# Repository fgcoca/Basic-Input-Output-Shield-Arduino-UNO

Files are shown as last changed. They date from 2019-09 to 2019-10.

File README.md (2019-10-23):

# **Escudo de entradas y salidas básicas para Arduino UNO**
# **(Basic Input Output Shield)**
Migración del Escudo de entradas y salidas básicas para Arduino UNO (Basic Input Output Shield) creado por Domingo Llorente del Departamento de Electrónica del IES Luis de Lucena de Guadalajara.

En las imágenes vemos una vista 3D del diseño en KiCAD y el aspecto real de la placa.

Captura | Fotografa
-- | --
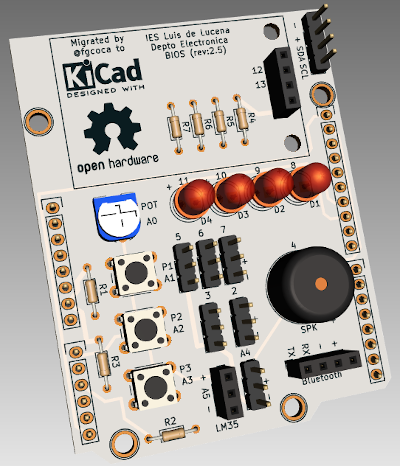
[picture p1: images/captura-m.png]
Imagen 1
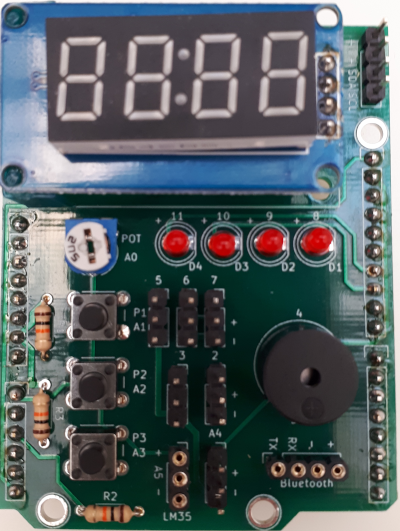
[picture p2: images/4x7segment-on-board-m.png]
Imagen 2
 | 

[1]: https://github.com/fgcoca/Basic-Input-Output-Shield-Arduino-UNO/blob/master/images/captura-m.png
[2]: https://github.com/fgcoca/Basic-Input-Output-Shield-Arduino-UNO/blob/master/images/4x7segment-on-board-m.png

## **Diseño de la PCB** 

En el enlace están todos los archivos KiCAD por si te apetece ver cómo se ha realizado el diseño de esta bonita Shield.

[BIOS_Shield_1.0_Migration](https://github.com/fgcoca/Basic-Input-Output-Shield-Arduino-UNO/tree/master/BIOS_Shield_1.0_Migration)

## **Memorias** 

* [Original en pdf](https://github.com/fgcoca/Basic-Input-Output-Shield-Arduino-UNO/blob/master/Manuales/original/BIOS_Shield_memoria_rev1.2.pdf)
* [Migrada en odt](https://github.com/fgcoca/Basic-Input-Output-Shield-Arduino-UNO/blob/master/Manuales/migrado/BIOS_Shield_migration_memory_rev1.0.odt)
* [Migrada en pdf](https://github.com/fgcoca/Basic-Input-Output-Shield-Arduino-UNO/blob/master/Manuales/migrado/BIOS_Shield_migration_memory_rev1.0.pdf)
* [Directorio de imágenes](https://github.com/fgcoca/Basic-Input-Output-Shield-Arduino-UNO/tree/master/images)

## **Programas para prueba de funcionalidad** 

* [Todo en un zip](https://github.com/fgcoca/Basic-Input-Output-Shield-Arduino-UNO/blob/master/BIOS_Programas_Demo_v1/BIOS_Programas_Demo_y_librerias.zip)
* [Directorio de sketches individuales y librerias](https://github.com/fgcoca/Basic-Input-Output-Shield-Arduino-UNO/tree/master/BIOS_Programas_Demo_v1)

## **Descripción del uso de pines** 

En el enlace tenemos los archivos svg y pdf del pinout de la PCB. El svg se facilita por si te apetece ver cómo se hace de forma sencilla un pinout en Inkscape.

* [Pinout en svg](https://github.com/fgcoca/Basic-Input-Output-Shield-Arduino-UNO/blob/master/pinout/BIOS_Shield_1.0_Migration.svg)
* [Pinout en pdf](https://github.com/fgcoca/Basic-Input-Output-Shield-Arduino-UNO/blob/master/pinout/BIOS_Shield_1.0_Migration.pdf)

## **Soporte 3D para el display de 4x7 segmentos** 

Directorio con el archivo FreeCAD de diseño del soporte y dos versiones stl del mismo.

* [Soporte](https://github.com/fgcoca/Basic-Input-Output-Shield-Arduino-UNO/tree/master/soporte)

### **Autor**

[Federico Coca Caba] (https://github.com/fgcoca)

### **Licencia**
<br /> <a rel="license" href="http://creativecommons.org/licenses/by-sa/4.0/">Creative Commons Attribution-ShareAlike 4.0 International License</a>.

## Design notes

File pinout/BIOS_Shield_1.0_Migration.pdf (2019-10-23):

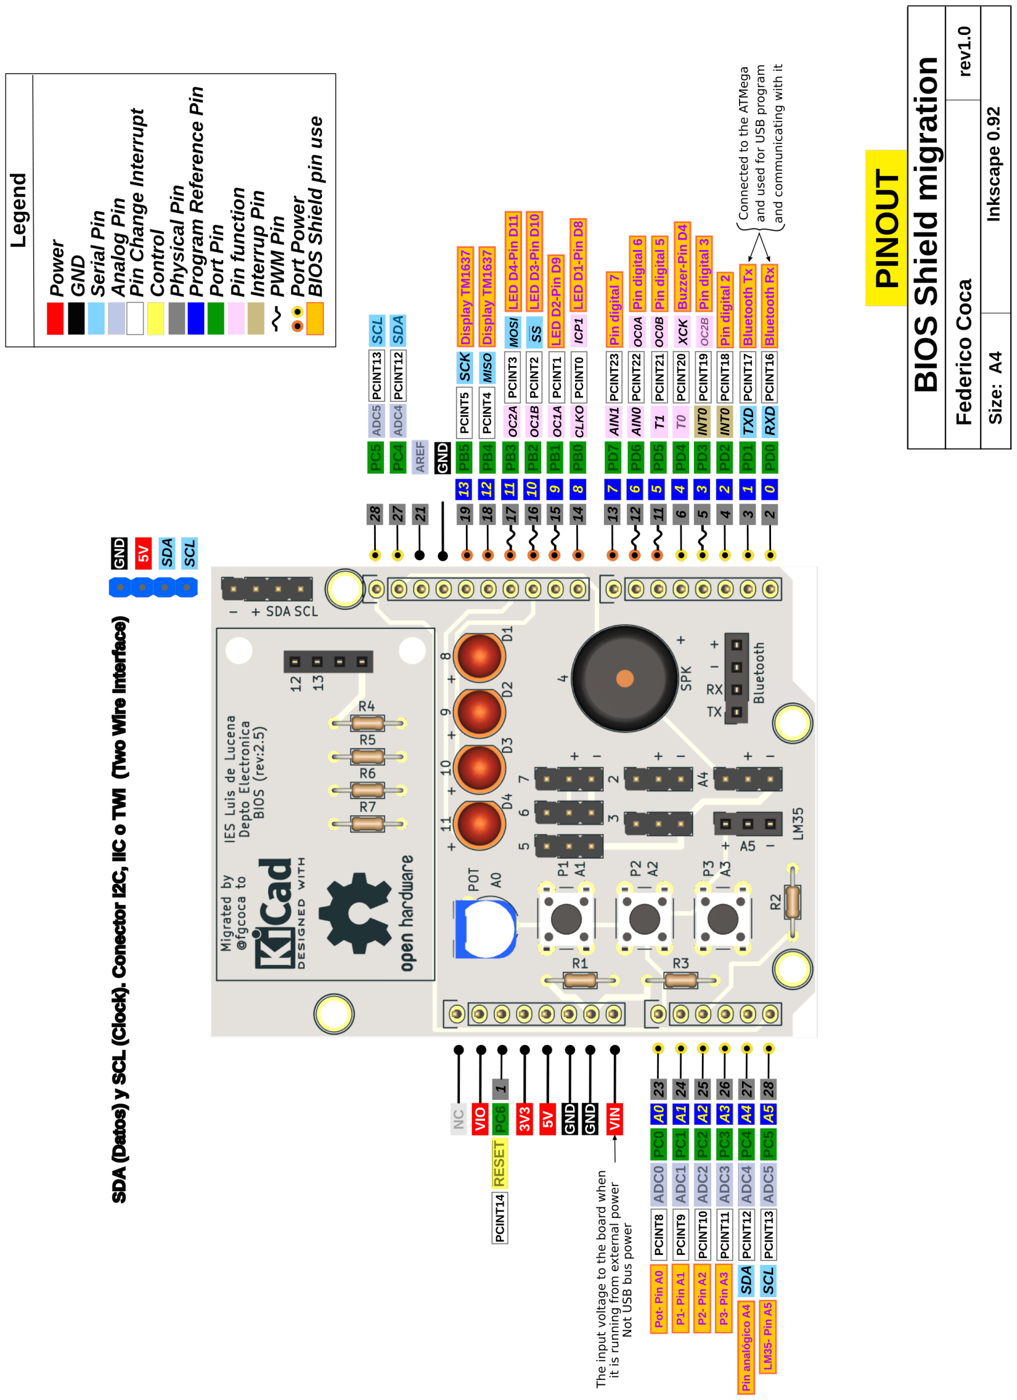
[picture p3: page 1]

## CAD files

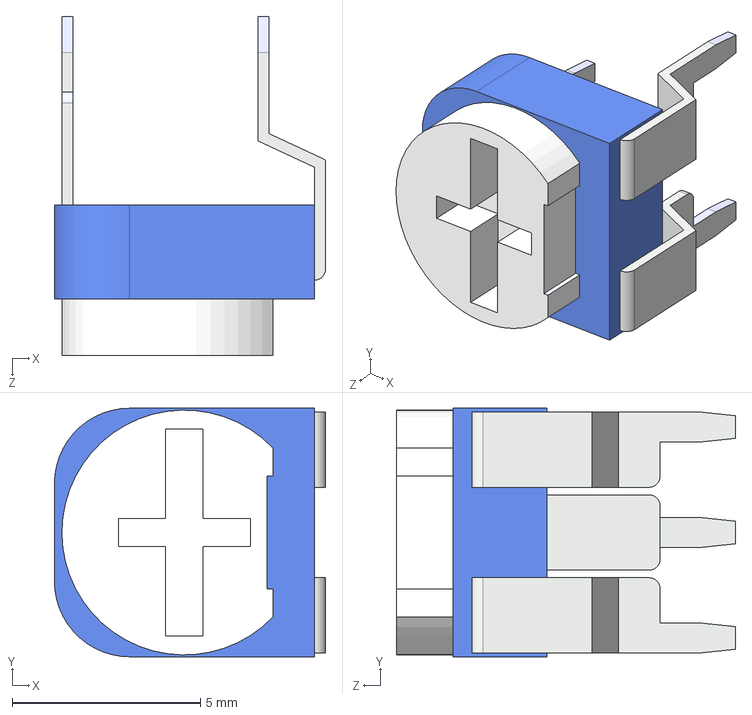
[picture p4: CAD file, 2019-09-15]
BIOS_Shield_1.0_Migration/modelos 3d/Potentiometer Blue.STEP
7.20 x 6.60 x 9.00 mm

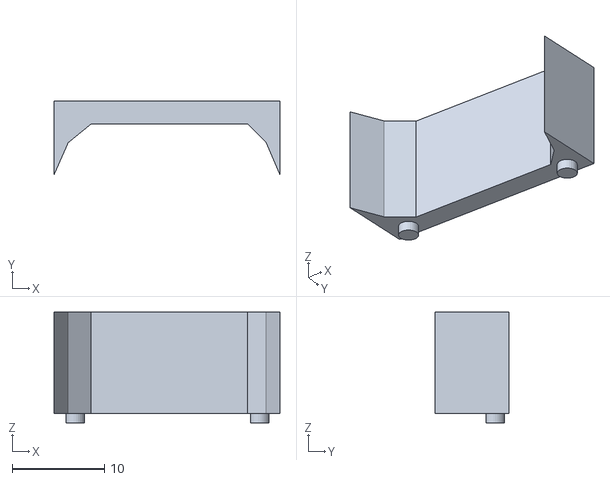
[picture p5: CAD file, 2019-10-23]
soporte/soporte-alto.stl
24.5 x 8.00 x 12.0

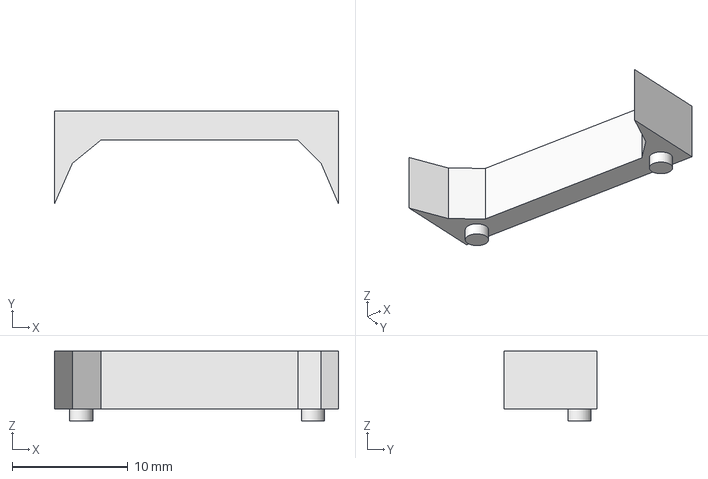
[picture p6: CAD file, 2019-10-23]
soporte/soporte.FCStd
24.5 x 8.00 x 6.00 mm

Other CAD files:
soporte/soporte.stl

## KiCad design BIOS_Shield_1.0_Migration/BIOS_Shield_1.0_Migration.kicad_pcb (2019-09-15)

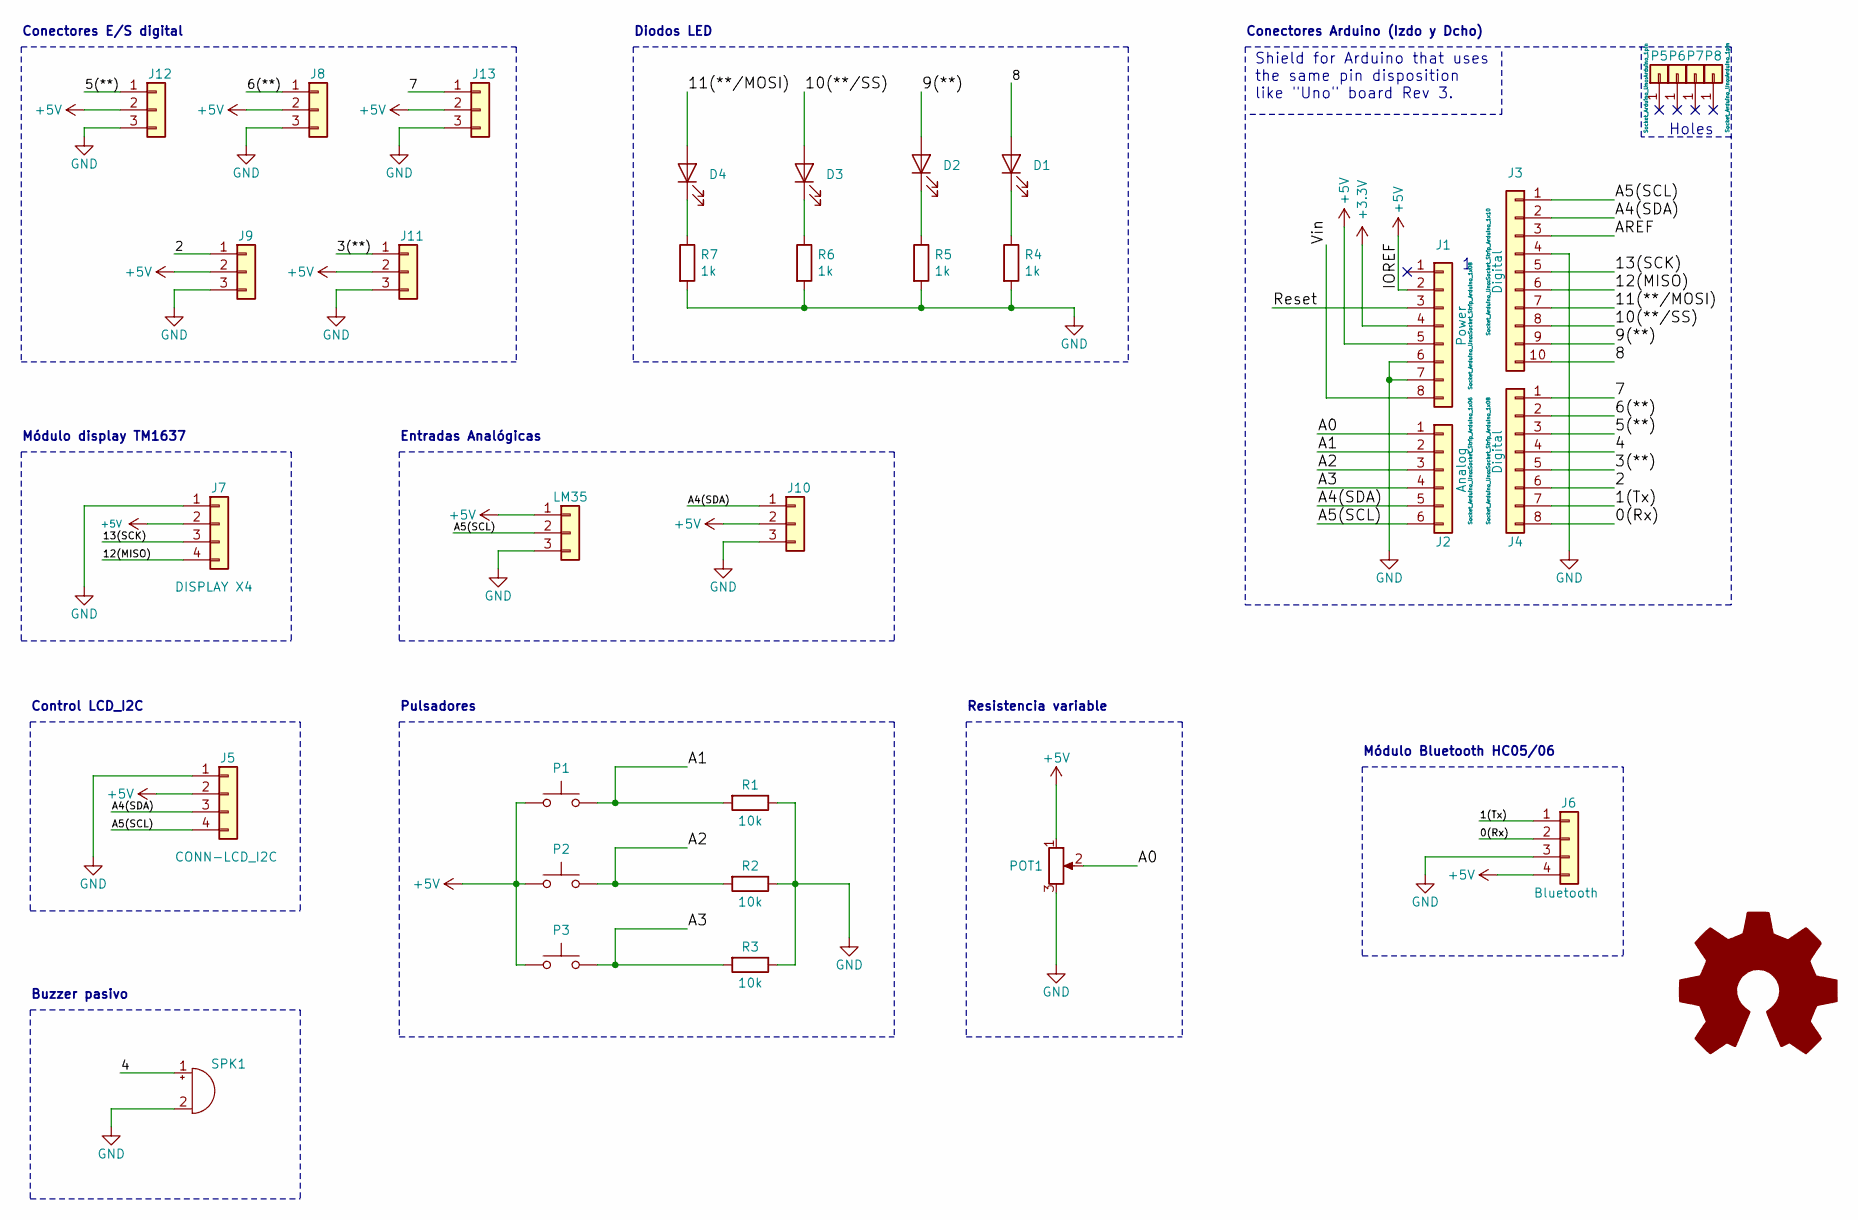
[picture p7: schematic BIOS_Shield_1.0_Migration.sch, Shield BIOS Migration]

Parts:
D1, D2, D3, D4: LED; LED_D5.0mm
J1: Power; Socket_Strip_Arduino_1x08
J2: Analog; Socket_Strip_Arduino_1x06
J3: Digital; Socket_Strip_Arduino_1x10
J4: Digital; Socket_Strip_Arduino_1x08
J5: CONN-LCD_I2C; PinSocket_1x04_P2.54mm_Vertical
J6: Bluetooth; PinSocket_1x04_P2.54mm_Vertical
J7: DISPLAY X4; TM1637
J8, J9, J10, J11, J12, J13: Conn_01x03; PinSocket_1x03_P2.54mm_Vertical
LM35: Conn_01x03; PinSocket_1x03_P2.54mm_Vertical
P1, P2, P3: SW_Push; SW_PUSH_6mm
P5, P6, P7, P8: CONN_01X01; Arduino_1pin
POT1: R_POT; Potentiometer_Piher_PT-6-V_Vertical
R1, R2, R3: 10k; R_Axial_DIN0204_L3.6mm_D1.6mm_P7.62mm_Horizontal
R4, R5, R6, R7: 1k; R_Axial_DIN0204_L3.6mm_D1.6mm_P7.62mm_Horizontal
SPK1: Buzzer; Buzzer_12x9.5RM7.6

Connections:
+3V3: J1.4
+5V: J1.2, J1.5, J5.2, J6.4, J7.2, J8.2, J9.2, J10.2, J11.2, J12.2, J13.2, LM35.1, P1.1, P2.1, P3.1, POT1.1; also elsewhere on the board
/0(Rx): J4.8, J6.2
/1(Tx): J4.7, J6.1
/2: J4.6, J9.1
/3(**): J4.5, J11.1
/4: J4.4, SPK1.1 (-); also elsewhere on the board
/5(**): J4.3, J12.1
/6(**): J4.2, J8.1
/7: J4.1, J13.1
/8: D1.2 (A), J3.10
/9(**): D2.2 (A), J3.9
/10(**/SS): D3.2 (A), J3.8
/11(**/MOSI): D4.2 (A), J3.7
/12(MISO): J3.6, J7.4
/13(SCK): J3.5, J7.3
/A0: J2.1, POT1.2; also elsewhere on the board
/A1: J2.2, P1.2, R1.2
/A2: J2.3, P2.2, R2.2
/A3: J2.4, P3.2, R3.2
/A4(SDA): J2.5, J3.2, J5.3, J10.1
/A5(SCL): J2.6, J3.1, J5.4, LM35.2
/AREF: J3.3
/Reset: J1.3
/Vin: J1.8
GND: J1.6, J1.7, J3.4, J5.1, J6.3, J7.1, J8.3, J9.3, J10.3, J11.3, J12.3, J13.3, LM35.3, POT1.3, R1.1, R2.1, R3.1, R4.2, R5.2, R6.2, R7.2, SPK1.2 (+); also elsewhere on the board
unnamed: D1.1 (K), R4.1
unnamed: D2.1 (K), R5.1
unnamed: D3.1 (K), R6.1
unnamed: D4.1 (K), R7.1

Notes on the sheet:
Holes
Shield for Arduino that uses the same pin disposition like "Uno" board Rev 3.
Conectores Arduino (Izdo y Dcho)
Conectores E/S digital
Diodos LED
Módulo display TM1637
Control LCD_I2C
Buzzer pasivo
Entradas Analógicas
Pulsadores
Resistencia variable
Módulo Bluetooth HC05/06

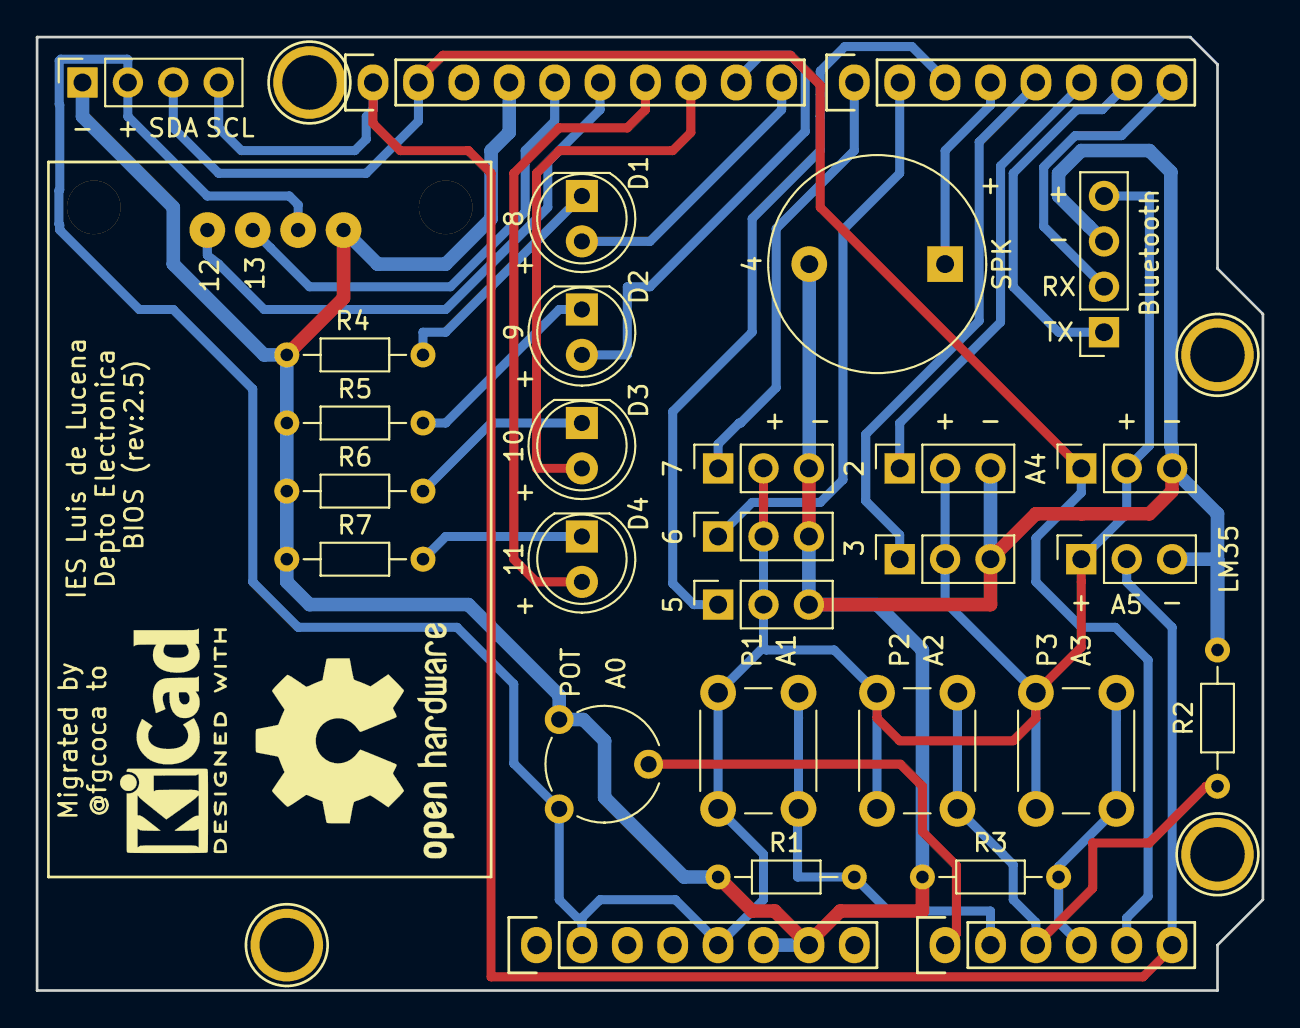
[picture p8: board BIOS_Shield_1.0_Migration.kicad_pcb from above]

Board: 2 copper layers, 68.6 x 53.3 mm, 34 parts (0 on the bottom side), 26 nets.

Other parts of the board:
POT: R_POT; Potentiometer_Piher_PT-6-V_Vertical
SPK: Buzzer; Buzzer_12x9.5RM7.6

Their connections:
+5V: POT.1; also elsewhere on the board
/4: SPK.1; also elsewhere on the board
/A0: POT.2; also elsewhere on the board
GND: POT.3, SPK.2; also elsewhere on the board

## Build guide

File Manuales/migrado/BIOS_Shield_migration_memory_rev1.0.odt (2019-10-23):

Escudo de entradas y salidas básicas para Arduino UNO

(Basic Input Output Shield)

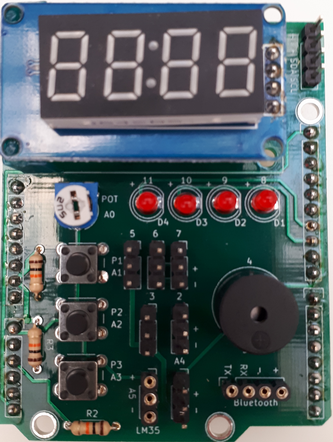
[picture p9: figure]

DOCUMENTACIÓN DE FUNCIONAMIENTO

Y

FABRICACIÓN

Autor: D.Llorente (2019) – Migrada a KiCAD por: @fgcoca

Rev 1.0

# 1. Descripción general

La placa de entradas y salidas básicas (BIOS shield) es una tarjeta diseñada para conectarse a la placa Arduino UNO y poder realizar prácticas generales de entrada y salida de datos, lectura de sensores y control de actuadores. Las características principales de la placa son:

Componente en la placa | Pines de conexión con Arduino
4 leds rojos de 3mm | 8,9,10 y 11
1 módulo de 4 displays de 7 segmentos (TM1637) | 12,13
3 pulsadores | A1,A2,A3
1 buzzer pasivo | 4
1 potenciómetro de 5k | A0
1 conector para módulo bluetooth HC05/06 | 0,1
1 conector para LCD-I2C u otro periférico I2C | SDA,SCL
1 conector para sensor de temperatura LM35 | A5 (*)
1 conector de entrada analógica | A4 (*)
6 conectores de E/S digital de propósito general | 2,3,5,6,7

(*) pines compartidos con el conector I2C.

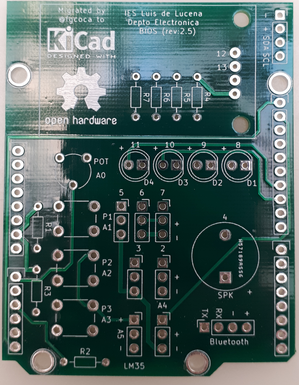
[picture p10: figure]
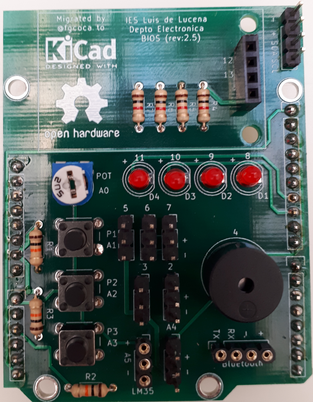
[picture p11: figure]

# 2. Esquema eléctrico completo

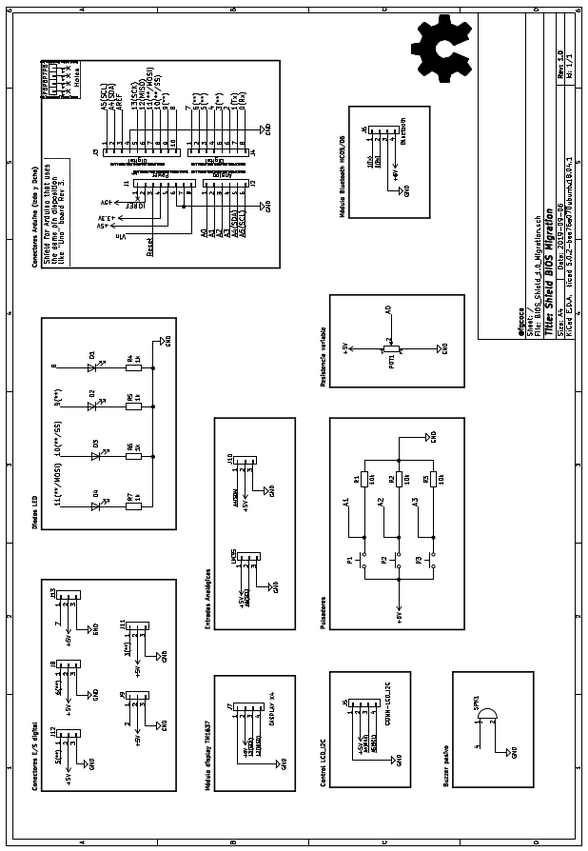
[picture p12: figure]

# 3. Descripción de circuitos por bloques

## 3.1 Pines de conexión con la placa Arduino UNO

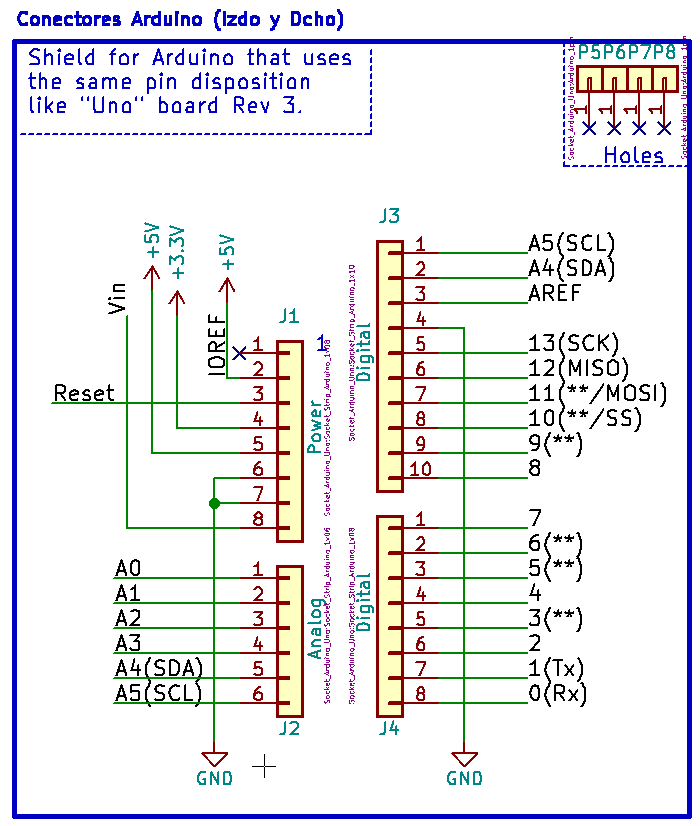
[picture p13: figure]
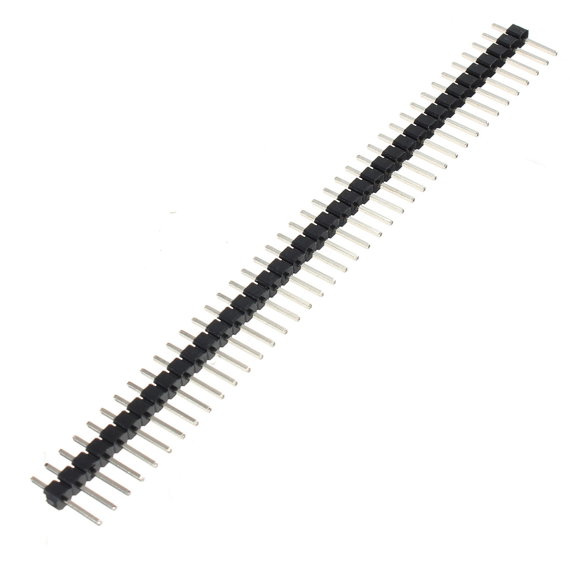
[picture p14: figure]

Se trata de cuatro conectores macho-macho de 2.54mm de paso que son utilizados para conectar la shield con la placa Arduino Uno. Se pueden usar también conectores de wrapping que son más largos.

## 3.2 Módulo de cuatro displays de siete segmentos

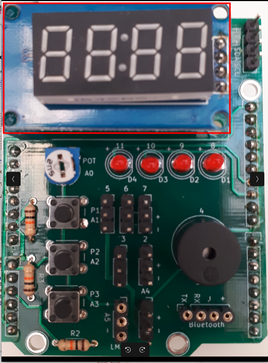
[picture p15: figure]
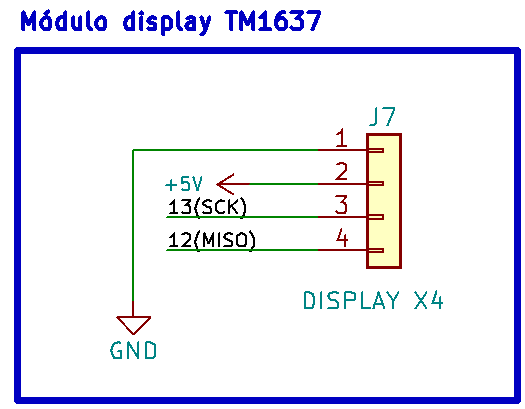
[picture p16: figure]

El módulo TM1637 es un driver para controlar displays de siete segmentos que utiliza el bus TWI (Two Wire Interface), por lo tanto, sólo son necesarios dos pines de Arduino (pines 12(DIO) y 13(CLK) para controlar todos los segmentos.

En este caso la placa consta de cuatro displays de 7 segmentos, más los dos segmentos centrales. El módulo se vende en varios colores (rojo,verde y azul), se puede regular su luminosidad mediante software y tiene un consumo entre 30mA y 80mA.

Información sobre el módulo y descarga de la librería en:
https://playground.arduino.cc/Main/TM1637/

## 3.3 Conector para display LCD-I2C

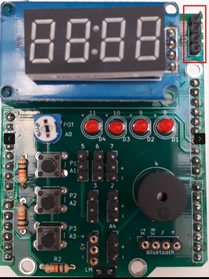
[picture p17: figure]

Se trata de un conector macho de cuatro pines donde tenemos disponibles los pines del bus I2C de la placa Arduino (SCL,SDA,Vcc y Gnd). Este conector está pensado para conectar directamente un módulo LCD- I2C y controlarlo mediante alguna de las librerías para Arduino existentes.

Existen varias librerías de control de displays lcd-i2c que tienen funciones distintas para configurar el módulo y enviar datos y/o comandos. De todas ellas una muy recomendable por su facilidad de uso es la PCF8574 que se puede descargar desde el propio IDE de Arduino o bien desde la web de su creador: http://www.mathertel.de/Arduino/LiquidCrystal_PCF8574.aspx

## 3.4 Leds

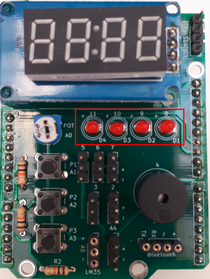
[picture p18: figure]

La placa dispone de cuatro leds de 3mm D1,D2,D3 y D4, activos a nivel alto y conectados a los pines de Arduino 8,9,10 y 11. Estos pines se deben configurar como salidas digitales con la instrucción pinMode(X,OUTPUT) o bien a través de los registros DDRB y PORTB.

Puedes encontrar más info sobre el manejo de estos registros en la web: https://www.arduino.cc/en/Reference/PortManipulation

## 3.5 Entradas analógicas

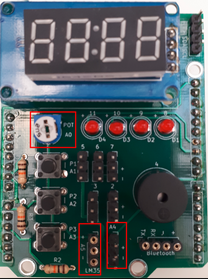
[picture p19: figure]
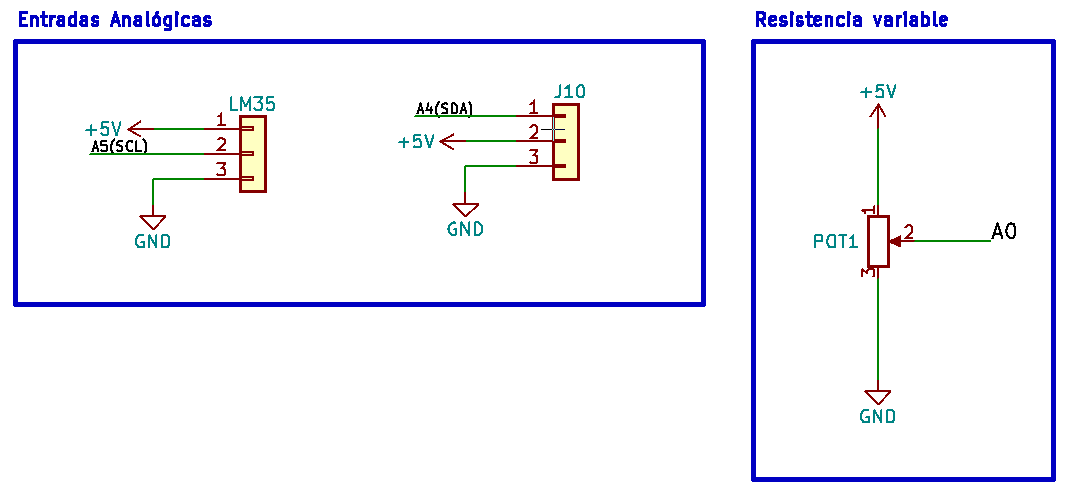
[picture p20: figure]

En la placa están conectadas las entradas analógicas A0, A4 y A5. La entrada A0 está conectada a un potenciómetro lineal de 5k con el que podemos variar la tensión de 0 a 5V. El conector LM35 (A5) está pensado para conectar directamente un sensor de temperatura LM35 y el conector J10 (A4) está libre para su uso con otro potenciómetro o sensor analógico.

## 3.6 Pulsadores

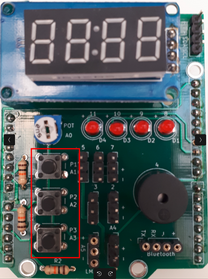
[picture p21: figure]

Este bloque está formado por tres pulsadores P1,P2 y P3 conectados a las entradas A1,A2 y A3 de Arduino que proporcionan un nivel alto (5V) al ser pulsados. Es necesario configurar estos pines como entradas digitales usando la instrucción pinMode(X,INPUT).

## 3.7 Buzzer pasivo

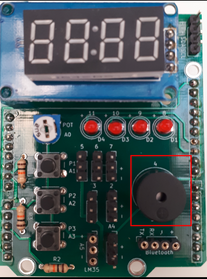
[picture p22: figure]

Se puede usar un buzzer activo o pasivo indistintamente. Los buzzers activos incorporan un pequeño oscilador que hace que únicamente haya que proporcionar un nivel alto para conseguir un sonido de una frecuencia determinada (pitido). Mientras se mantenga el nivel alto se mantendrá el pitido. Por el contrario los buzzers pasivos funcionan como un pequeño altavoz, es decir, se necesita una onda de una frecuencia determinada para generar un sonido.

## 3.8 Conectores multipropósito de E/S digital

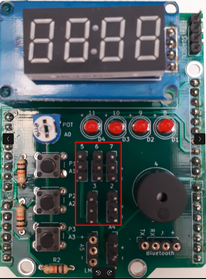
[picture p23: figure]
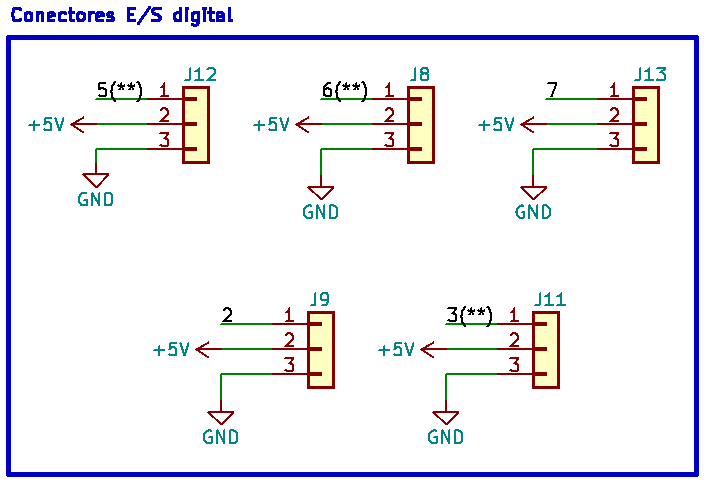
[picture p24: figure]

En el centro de la placa se encuentran una serie de conectores macho de tres pines que están conectados directamente a los pines digitales 2,3,5,6 y 7 de Arduino.

Estos conectores se pueden configurar como entradas o salidas digitales para utilizarlos en nuestros proyectos. Algunos de los periféricos que podemos conectar son: receptores de IR, sensores PIR, servo motores, tiras o matrices de leds, motores DC o PAP (usando el driver apropiado), sensores de distancias SRF04, etc.

## 3.9 Conector para módulo Bluetooth

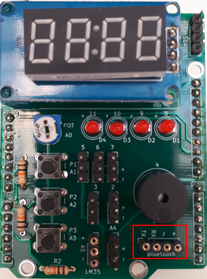
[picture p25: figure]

En la parte inferior de la placa se encuentra un conector hembra de cuatro pines donde podemos conectar directamente un módulo Bluetooth del tipo HC05/06.

El módulo Bluetooth emparejado con nuestro teléfono móvil proporciona una comunicación bidireccional muy útil para enviar comandos a la placa de forma inalámbrica y/o recibir datos de sensores, etc.

Estos módulos transforman la señal del puerto serie de Arduino a Bluetooth de forma transparente para el usuario, por lo tanto, enviar datos de forma inalámbrica es tan sencillo como enviar un dato por el puerto serie.

¡Importante! Los pines de Rx y Tx están conectados directamente a los pines 0(Rx) y 1(Tx) de Arduino, por lo tanto, es obligatorio desconectar el módulo Bluetooth cuando se cargue el programa en la placa.

# 4. Relación de programas de ejemplo

Programa | Descripción
BIOS_demo_Leds | Secuencia de leds en bucle (Izda->Dcha->Blink) desplaza un led a derecha
BIOS_demo_buzzer | Notas musicales en el buzzer al pulsar P1 y pitidos con P3
BIOS_demo_pulsaLeds | Descripción: Secuencia de leds con cada pulsación: P1: desplaza un led de izda a dcha P2: desplaza un led de dcha a izda P3: parpadeo
BIOS_demo_ReadPot_Serial_7seg | Visualización del valor digital del del Pot de la placa en los displays y en el terminal serie. Utiliza la librería TM1637 disponible en https://github.com/avishorp/TM1637
BIOS_demo_disp7seg_contador | Contador de cuatro dígitos en los displays
BIOS_demo_disp7seg_mensajes | Mensajes “hola” y “27ºC” alternativos en displays
BIOS_demo_lcd_I2C | Mensajes en display LCD-I2C con chip PCF8574 Utiliza la librería LiquidCrystal_PCF8574 v1.1.0 by Mathias Hertel. Link de descarga de la librería: http://www.mathertel.de/Arduino/LiquidCrystal_PCF8574.aspx
BIOS_demo_LM35_Serial | Envía la temperatura del sensor LM35 en ºC al puerto serie
BIOS_demo_Bluetooth | Lee el dato en el puerto serie y enciende/apaga los leds de la placa. A->Apagar leds, E->Encender leds
Link de descarga de todos los programas en .zip: https://www.dropbox.com/s/caeqmio5z7mhgyi/BIOS_Programas_Demo_rev1.zip?dl=0 (https://github.com/fgcoca/Basic-Input-Output-Shield-Arduino-UNO/blob/master/BIOS_Programas_Demo_v1/BIOS_Programas_Demo_y_librerias.zip)

# 5. Diseño hardware

## PCB completa

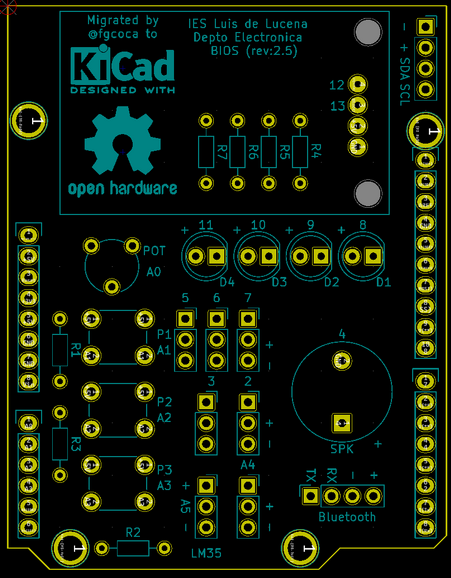
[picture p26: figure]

Toda la información de la migración de la PCB, incluidos los gerber de fabricación, está disponible en:

https://github.com/fgcoca/Basic-Input-Output-Shield-Arduino-UNO/tree/master/BIOS_Shield_1.0_Migration

Los archivos Gerber de fabricación de la placa original se pueden descargar en el siguiente enlace: https://www.dropbox.com/s/1lazdpn8fwu6f0v/BIOS_Gerber_files_RS274X_fabricado_PCWAY.zip?dl=0

(https://www.dropbox.com/s/1lazdpn8fwu6f0v/BIOS_Gerber_files_RS274X_fabricado_PCWAY.zip?dl=0)

# 6. Lista de materiales

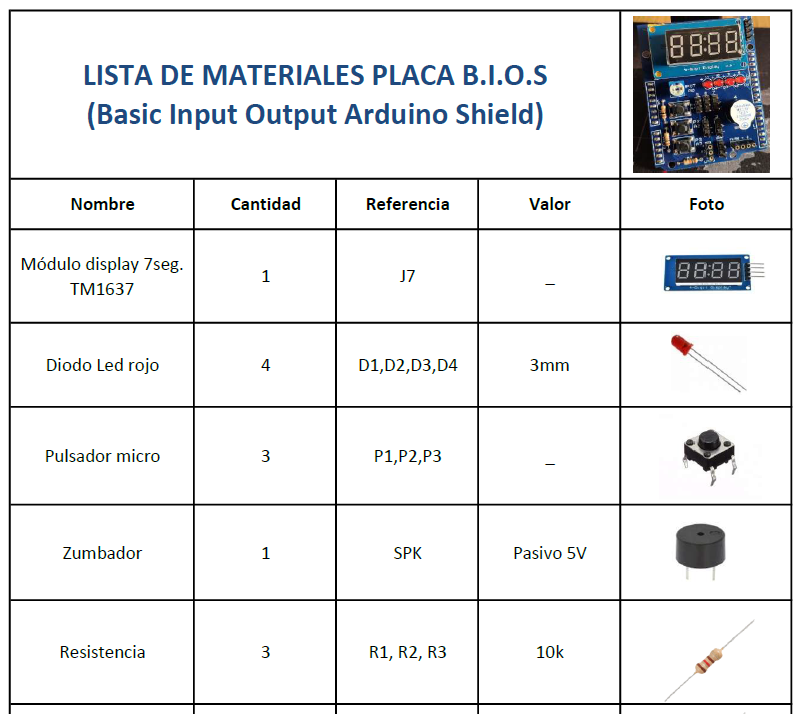
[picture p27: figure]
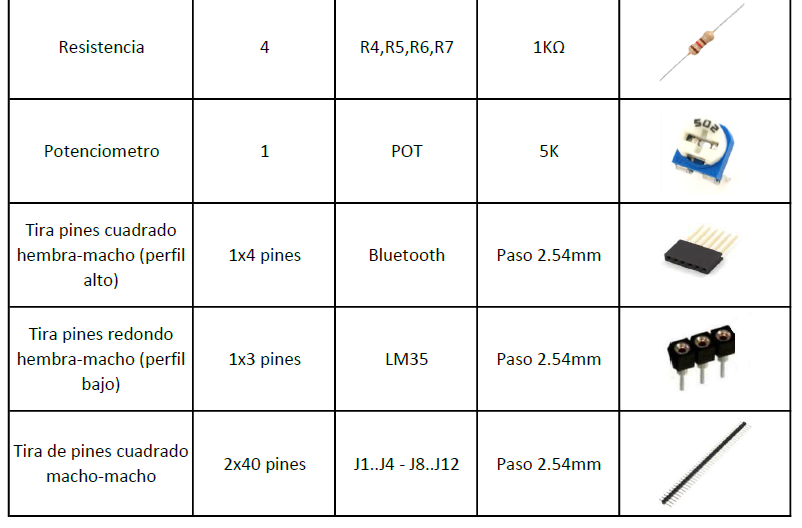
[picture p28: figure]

(https://www.dropbox.com/s/1lazdpn8fwu6f0v/BIOS_Gerber_files_RS274X_fabricado_PCWAY.zip?dl=0)

# 7. Galería de imágenes

## PCB + componentes básicos

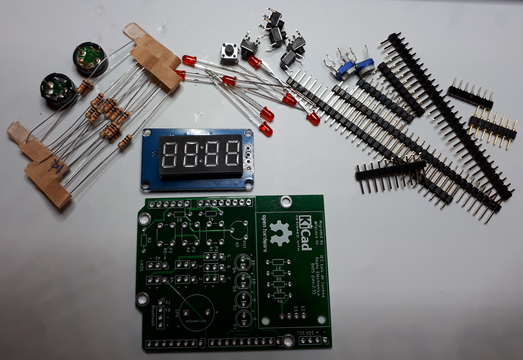
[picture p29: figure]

## Placa montada

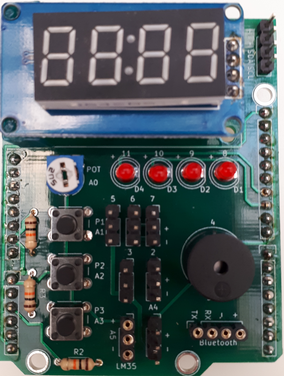
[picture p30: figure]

## PCB por ambas caras

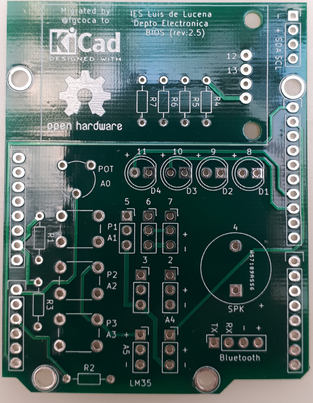
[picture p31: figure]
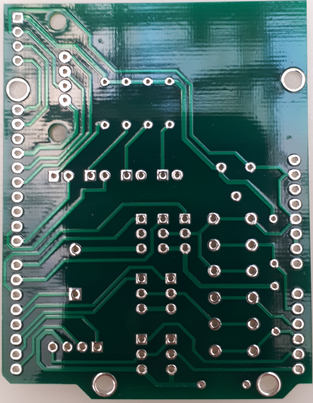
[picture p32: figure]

# 8. Licencia de uso Creative Commons

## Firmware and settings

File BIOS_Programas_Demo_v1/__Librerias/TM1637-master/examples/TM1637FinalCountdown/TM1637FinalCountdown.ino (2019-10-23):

#include <TM1637Display.h>

// Module connection pins (Digital Pins)
#define CLK 2
#define DIO 3

// The amount of time (in milliseconds) between tests
#define TEST_DELAY   1000

TM1637Display display(CLK, DIO);

int count = 9999;
uint8_t data[] = {0, 0, 0, 0};
  
void setup() {
}

void loop() {
  display.setBrightness(0x0f);

  data[3] = display.encodeDigit(count/1 % 10);
  data[2] = display.encodeDigit(count/10 % 10);
  data[1] = display.encodeDigit(count/100 % 10);
  data[0] = display.encodeDigit(count/1000 % 10);
  display.setSegments(data);

  if(count <= 0) {
    count = 9999;
  } else {
    count--;
  }
  
  delay(TEST_DELAY);
}

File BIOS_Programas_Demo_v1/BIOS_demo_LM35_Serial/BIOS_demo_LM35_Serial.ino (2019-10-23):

//----------------------------------------------------------------------------
// Programa: BIOS_demo_LM35_Serial.ino (Arduino UNOrev3 + shield BIOS + lm35)
// Autor: D.Llorente (julio-2019)
// Descripción: Envía la temperatura en ºC al puerto serie  
// Nota: El sensor LM35 proporciona un valor de tensión proporcional a la
// temperatura existente a razón de 10mV/grado                 
//----------------------------------------------------------------------------
#include <TM1637Display.h>
#define POT  A0
#define LM35 A5
#define P1   A1
#define P2   A2
#define P3   A3
#define LED1 8
#define LED2 9
#define LED3 10
#define LED4 11
#define BUZZ 4
#define RETARDO  500

int   valorADC = 0;
float voltios  = 0.0;
float grados   = 0.0;

void setup() {
  Serial.begin(9600);
  pinMode (P1, INPUT);
  pinMode (P2, INPUT);
  pinMode (P3, INPUT);
  pinMode (LED1, OUTPUT);
  pinMode (LED2, OUTPUT);
  pinMode (LED3, OUTPUT);
  pinMode (LED4, OUTPUT);
  pinMode(BUZZ, OUTPUT);
  // Apagar leds y buzzer
  digitalWrite(LED1,LOW);
  digitalWrite(LED2,LOW);
  digitalWrite(LED3,LOW);
  digitalWrite(LED4,LOW);
  digitalWrite(BUZZ,LOW);
  // Mensaje a serial
  Serial.println("Programa: BIOS_demo_temp_LM35.ino");
  Serial.println("Lectua de temp del sensor LM35");
  Serial.println("-------------------------------");
}

void loop() {
 valorADC = analogRead(LM35);
 voltios = (valorADC/1023.0)*5.0;  
 //grados = voltios*100;             // para 10mV/grado      
 grados = (5.0 * valorADC * 100.0)/1024.0;      
 Serial.print("Valor ADC..: ");
 Serial.println(valorADC);
 Serial.print("Voltios....: ");
 Serial.println(voltios);
 Serial.print("Temperatura: ");
 Serial.print(grados);
 Serial.println(" grados");
 Serial.println("---------------------");
 delay(5000);
}
